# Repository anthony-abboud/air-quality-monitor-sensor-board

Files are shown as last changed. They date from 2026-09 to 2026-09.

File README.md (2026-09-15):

# AirQualityMonitor-SensorBoard (Pico2JSTboard)

Custom PCB for Lehigh University's Sustainable Engineering Club Air Quality Monitor project. Integrates a Raspberry Pi Pico 2 W with a Sensirion SEN54 environmental sensor for low-cost, IoT-connected indoor air quality monitoring.

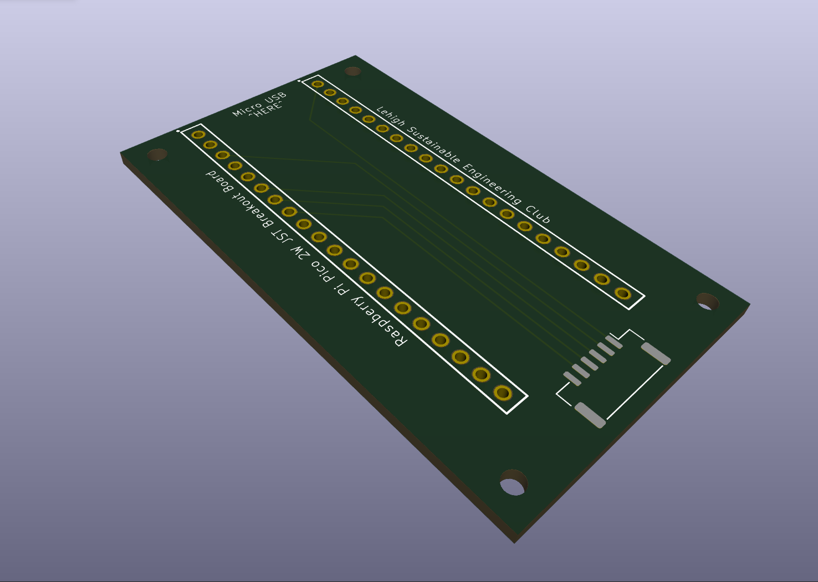
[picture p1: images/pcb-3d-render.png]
PCB 3D render


## Overview

The original prototype connected the Pico 2 W to the SEN54 sensor via breadboard and loose cabling. This board replaces that setup with a compact, pluggable assembly: two socket headers accept the Pico 2 W directly, and an onboard JST connector interfaces with the SEN54 over a short cable, eliminating fragile wiring from the prototype.

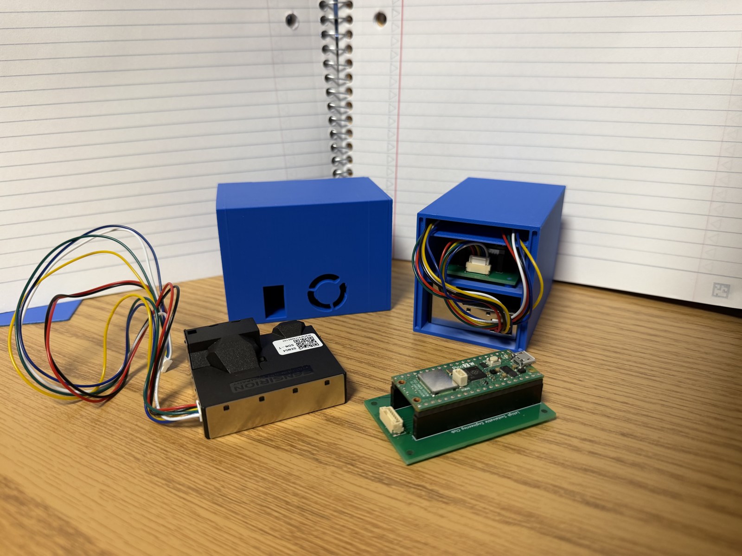
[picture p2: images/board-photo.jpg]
Assembled hardware


## Components

| Part | Manufacturer | Notes |
|---|---|---|
| SEN54 | Sensirion | Environmental sensor node — PM, RH/T, VOC measurements |
| Raspberry Pi Pico 2 W (with headers) | Raspberry Pi | Wi-Fi–enabled microcontroller |
| 5V power supply (microUSB) | — | Powers the board via the Pico's VBUS |

## Wiring

| SEN54 Pin (JST GHR-06V-S) | Function | Pico 2 W Pin | Net |
|---|---|---|---|
| 1 | VDD | 40 (VBUS) | `VDD_5V` |
| 2 | GND | 3 (GND) | `GND` |
| 3 | SDA | 6 (GP4, I2C0 SDA) | `I2C0_SDA` |
| 4 | SCL | 7 (GP5, I2C0 SCL) | `I2C0_SCL` |
| 5 | SEL | 8 (GND) | `GND` — tied low to select I2C mode |
| 6 | NC | — | not connected |

## Schematic

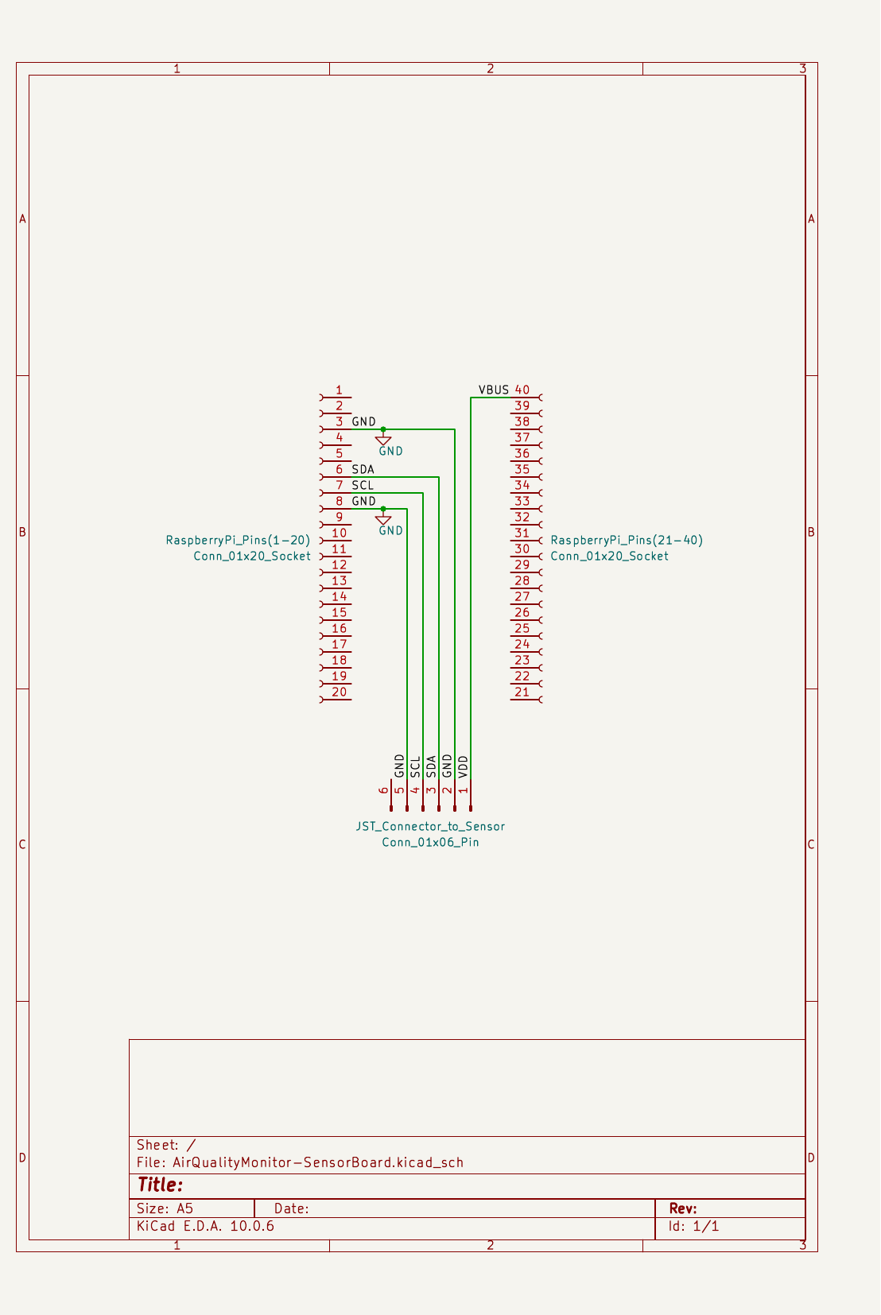
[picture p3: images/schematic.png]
Schematic


## PCB Layout

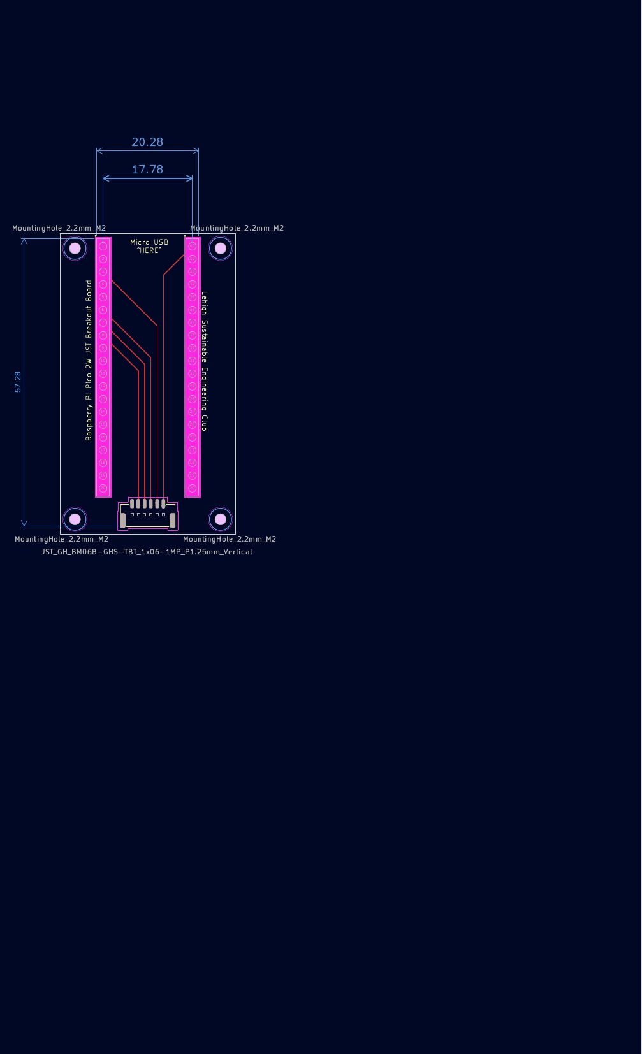
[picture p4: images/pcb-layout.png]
PCB layout


## Design Notes

- Two socket headers, manually spaced to fit the Pico 2 W, replace the breadboard and loose cabling from the original prototype.
- The onboard JST connector interfaces with the SEN54 over a cable, keeping the sensor off-board for flexible mounting.
- The SEN54's SEL pin is tied to GND to select I2C communication mode (rather than UART).
- All ground connections (sensor GND, SEL, and Pico pin 3) share a single common `GND` net.

## Repository Structure

```
/hardware   KiCad project files (schematic, PCB layout, fabrication outputs)
/images     Rendered images used in this README
/firmware   Microcontroller code (in active development)
```

## Status

Board designed, fabricated, and assembled. Firmware is in active development.

## References

- [Raspberry Pi Pico 2 W Datasheet](https://datasheets.raspberrypi.com/picow/pico-2-w-datasheet.pdf)
- [Sensirion SEN5x Datasheet](https://sensirion.com/media/documents/6791EFA0/62A1F68F/Sensirion_Datasheet_Environmental_Node_SEN5x.pdf)

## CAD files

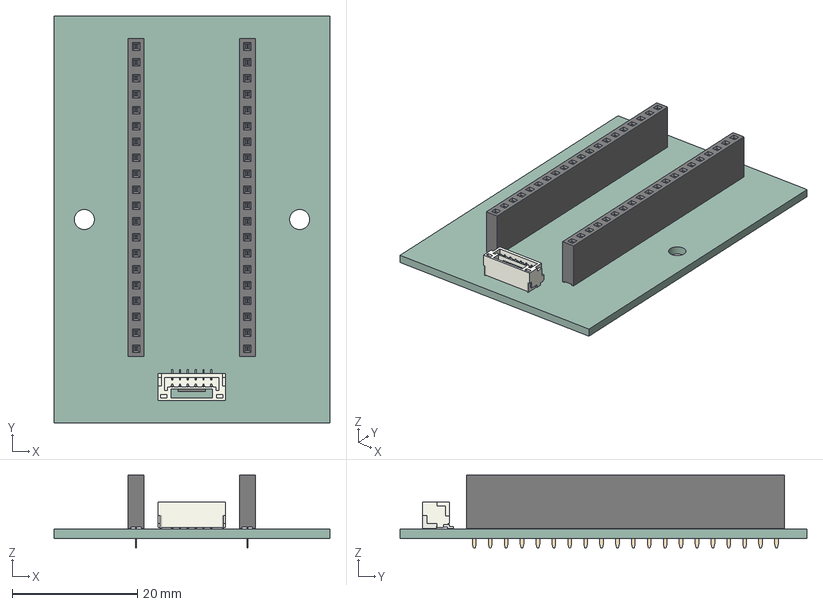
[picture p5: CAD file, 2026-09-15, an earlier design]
Old Versions/Pico2JSTboard.step
44.0 x 65.0 x 11.6 mm
JST_GH_BM06B-GHS-TBT_1x06-1MP_P1.25mm_Vertical
PinSocket_1x20_P2.54mm_Vertical x 2
Pico2JSTboard_PCB

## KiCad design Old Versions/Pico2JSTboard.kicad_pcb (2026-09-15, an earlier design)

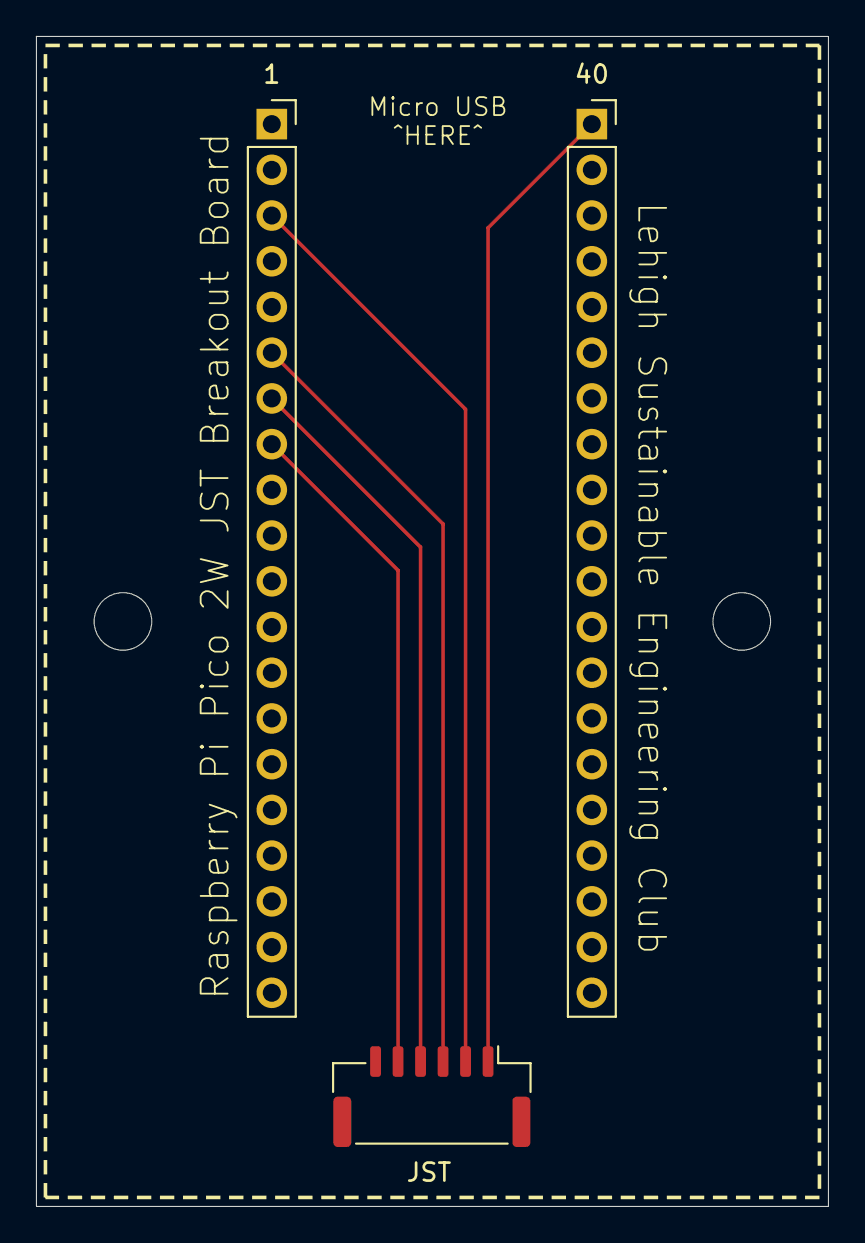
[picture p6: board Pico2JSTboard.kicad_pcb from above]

Board: 2 copper layers, 44.0 x 65.0 mm, 3 parts (0 on the bottom side), 5 nets.

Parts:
1, 40: PinSocket_1x20_P2.54mm_Vertical
JST: JST_GH_BM06B-GHS-TBT_1x06-1MP_P1.25mm_Vertical

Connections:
Net1: 40.1, JST.1
Net2: 1.3, JST.2
Net3: 1.6, JST.3
Net4: 1.7, JST.4
Net5: 1.8, JST.5

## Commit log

2026-09-15 Initial commit: Pico2JSTboard hardware design
    [AirQualityMonitor-SensorBoard.kicad_pcb, AirQualityMonitor-SensorBoard.kicad_sch, Pico2JSTboard(V2).kicad_pcb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]
2026-09-15 Update information in README
    Clarify ground connection details in README.
2026-09-15 Update page sizes
    [AirQualityMonitor-SensorBoard.kicad_pcb, AirQualityMonitor-SensorBoard.kicad_sch]
2026-09-15 Add README images
    [AirQualityMonitor-SensorBoard.kicad_sch]
